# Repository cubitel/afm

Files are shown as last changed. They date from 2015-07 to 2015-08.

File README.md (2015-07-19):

DIY Atomic Force Microscope
---------------------------

DIY Atomic Force Microscope / Scanning Tunneling Microscope project.
More information can be found in [Project page](http://npk.cubitel.org/?/hardware/afm) (in Russian).

Please note that this project is under development yet.

### Hardware

Hardware folder contains hardware design files.

_Design tools_
- Schematic, PCB -- KiCAD
- 3D parts -- FreeCAD

### Firmware

Firmware folder contains firmware source files for STM32F407 controller.
Firmware using FreeRTOS and STM32 USB stack (bundled with the source tree).

### Software

Software folder contains control application source files.
Software using wxWidgets and libusb and designed to be cross-platform,
but current Makefile assumes Windows/MinGW.

_Build requirements_
- TDM-GCC
- wxWidgets
- libusb

### License
GPLv3

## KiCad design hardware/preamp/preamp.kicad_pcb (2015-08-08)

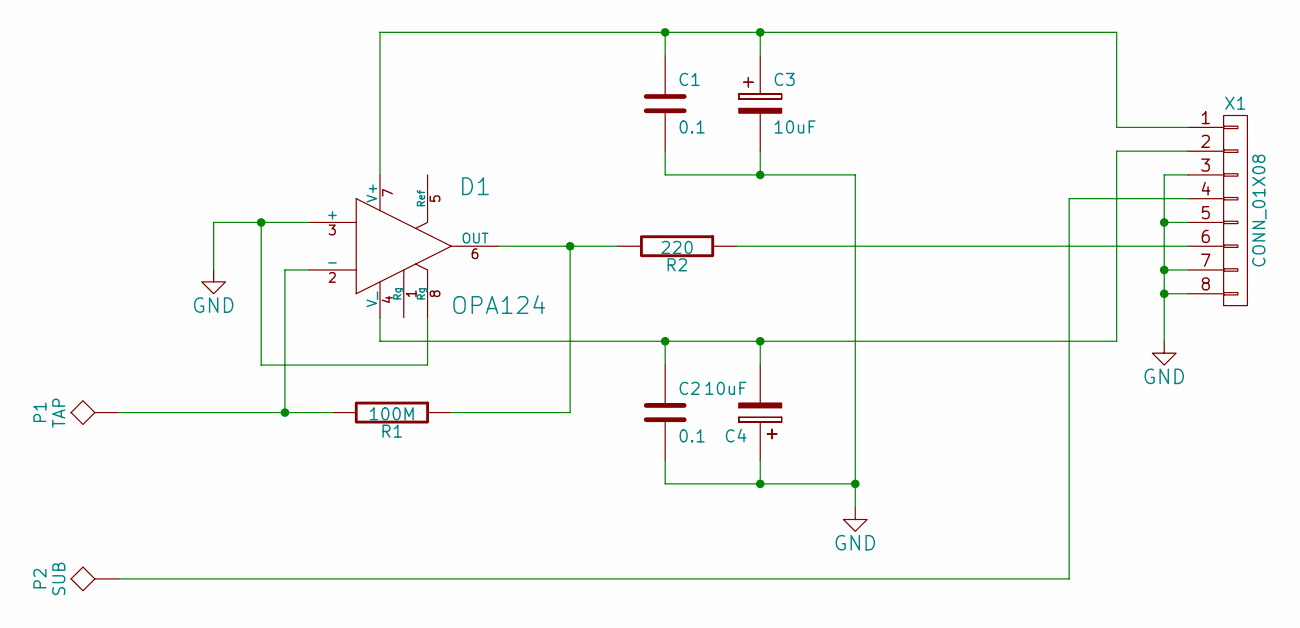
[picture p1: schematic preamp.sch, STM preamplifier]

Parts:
C1, C2: 0.1; C_0805
C3, C4: 10uF; TantalC_SizeA_EIA-3216_HandSoldering
D1: OPA124; SOIC-8-N
P1: TAP; Pin_Header_Straight_1x01
P2: SUB; Pin_Header_Straight_1x01
R1: 100M; R_0805
R2: 220; R_0805
X1: CONN_01X08; Pin_Header_Straight_1x08

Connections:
GND: C1.2, C2.2, C3.2, C4.1, D1.3 (+), D1.8 (Rg), X1.3, X1.5, X1.7, X1.8
unnamed: C1.1, C3.1, D1.7 (V+), X1.1
unnamed: C2.1, C4.2, D1.4 (V_), X1.2
unnamed: D1.2 (-), P1.1, R1.2
unnamed: D1.6 (OUT), R1.1, R2.2
unnamed: P2.1, X1.4
unnamed: R2.1, X1.6

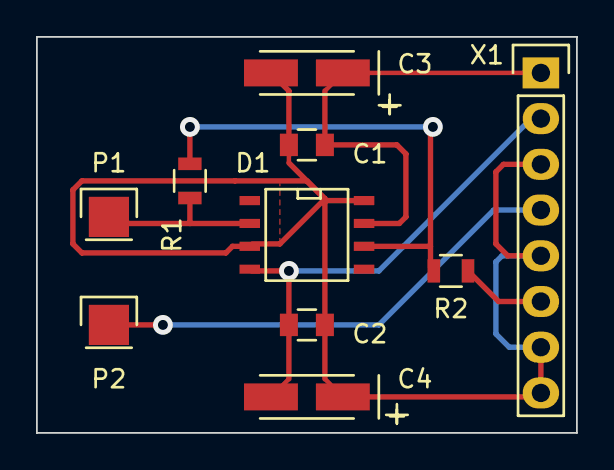
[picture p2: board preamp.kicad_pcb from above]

Board: 2 copper layers, 30.0 x 22.0 mm, 10 parts (0 on the bottom side), 7 nets.

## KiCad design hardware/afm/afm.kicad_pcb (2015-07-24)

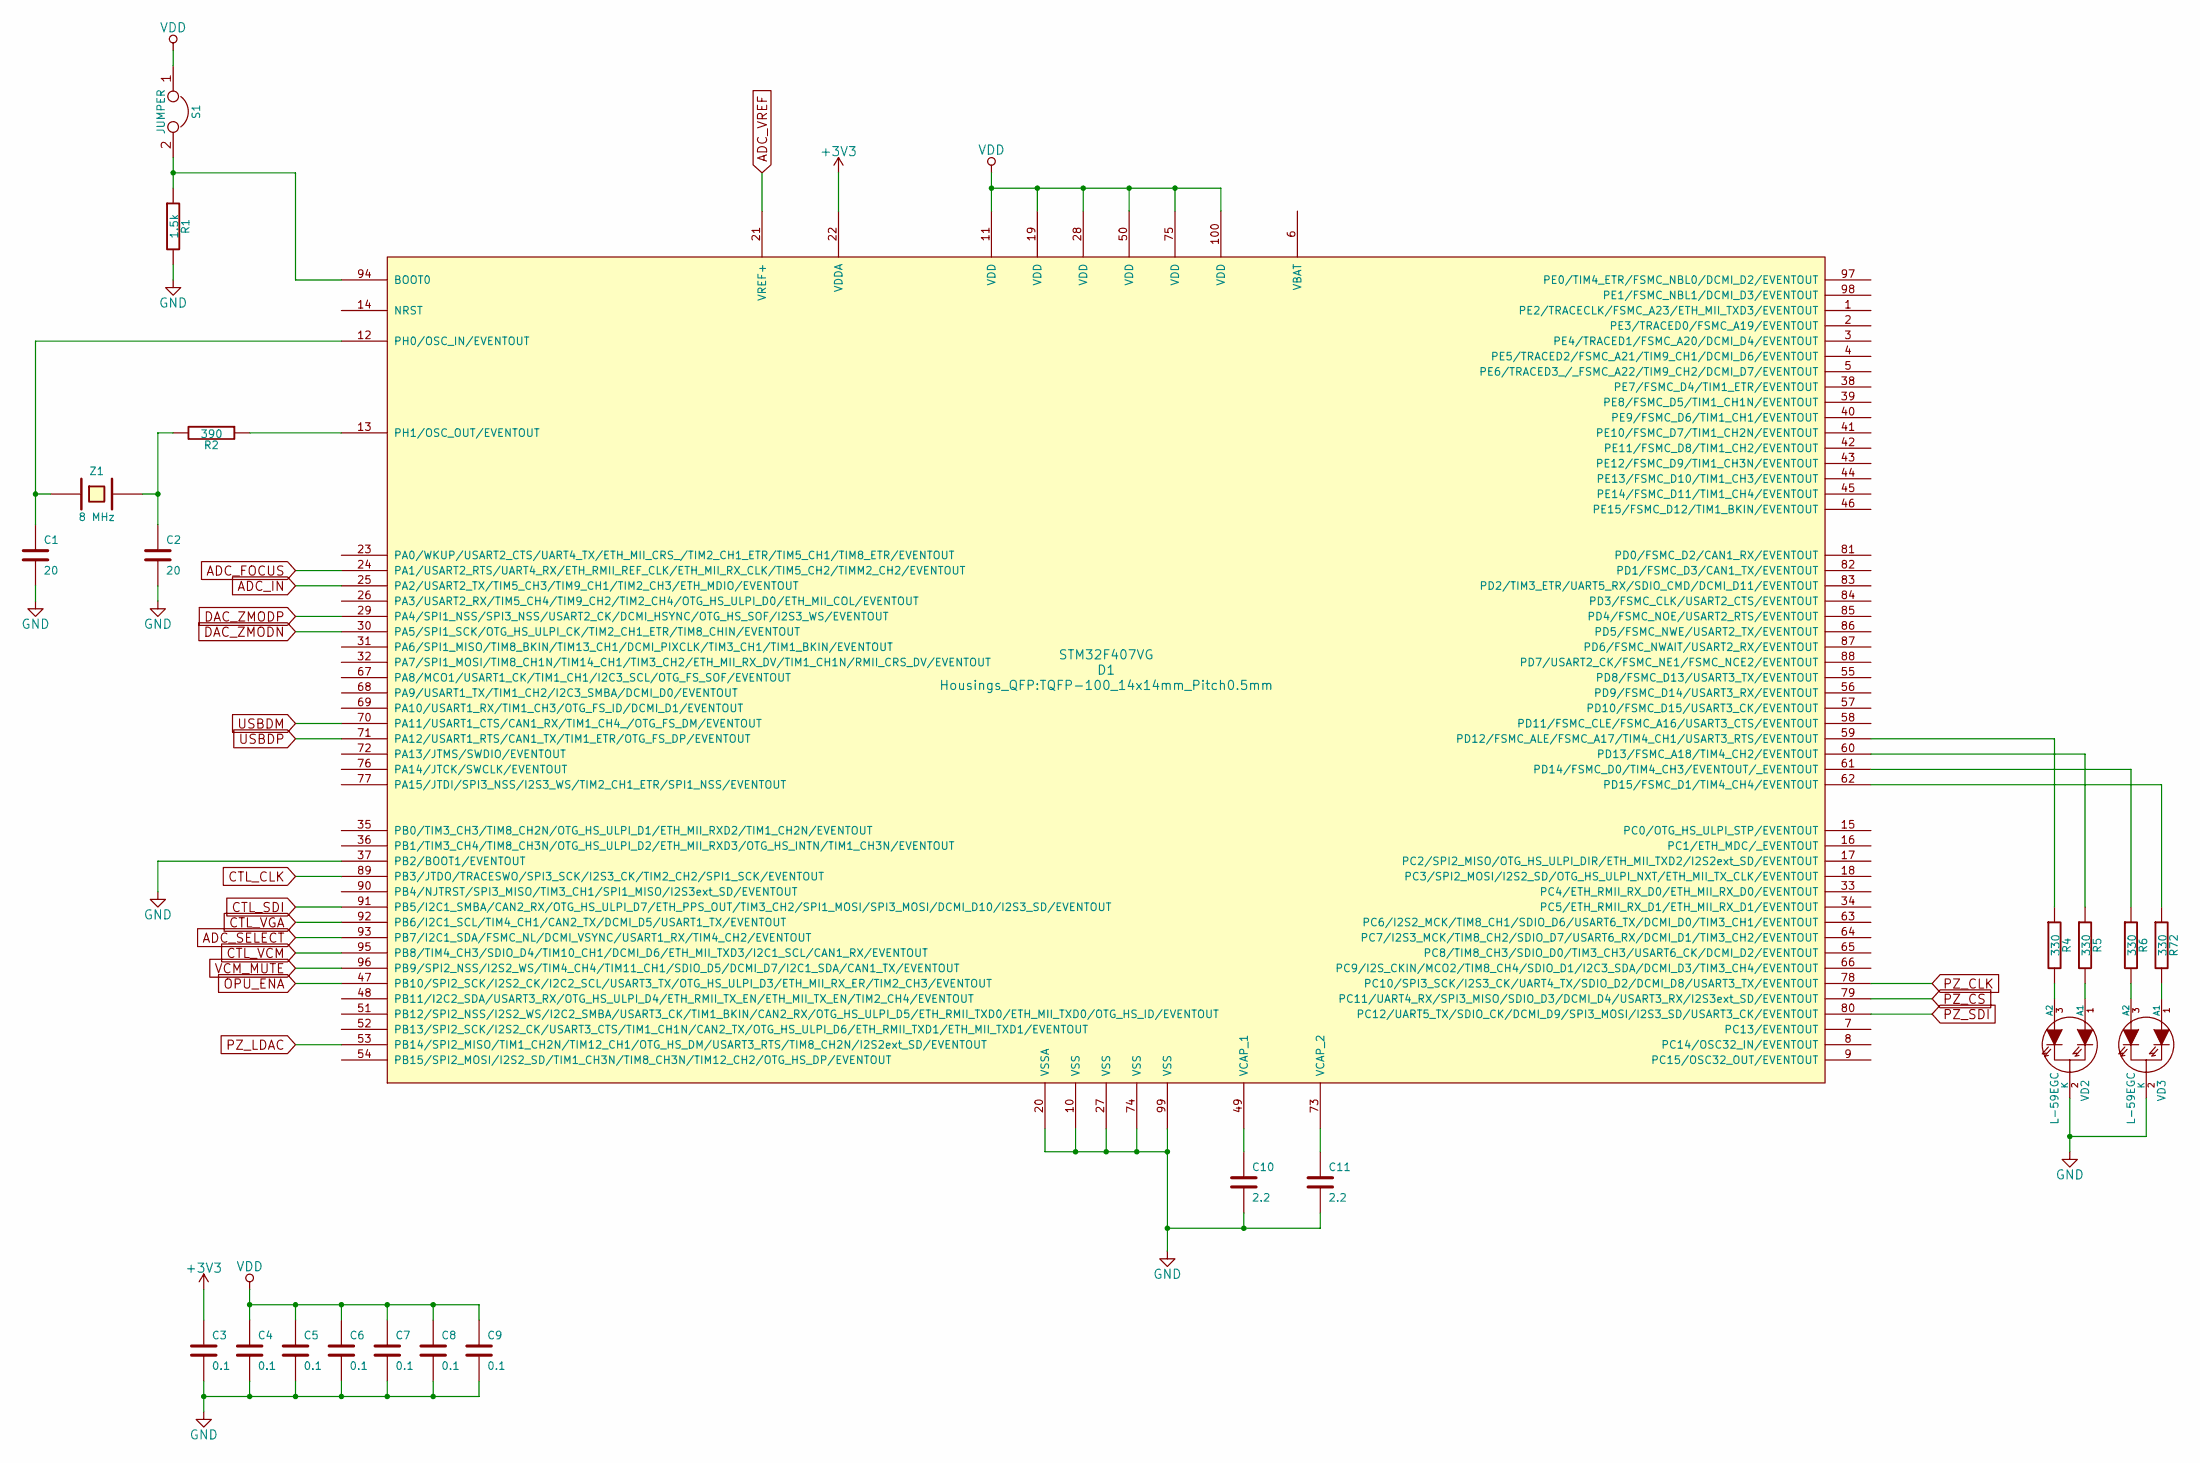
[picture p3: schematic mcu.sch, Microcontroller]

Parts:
C1, C2: 20; C_0603_HandSoldering
C3, C4, C5, C6, C7, C8, C9: 0.1; C_0603_HandSoldering
C10, C11: 2.2; C_0805_HandSoldering
D1: STM32F407VG; TQFP-100_14x14mm_Pitch0.5mm
R1: 1.5k; R_0603_HandSoldering
R2: 390; R_0603_HandSoldering
R4, R5, R6, R72: 330; R_0603_HandSoldering
S1: JUMPER; Pin_Header_Straight_1x02
VD2, VD3: L-59EGC; LED-5MM-3
Z1: 8 MHz; Crystal_HC49-SD_SMD

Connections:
+3V3: C3.1, D1.22 (VDDA); also elsewhere on the board
ADC_FOCUS: D1.24 (PA1/USART2_RTS/UART4_RX/ETH_RMII_REF_CL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); also elsewhere on the board
ADC_IN: D1.25 (PA2/USART2_TX/TIM5_CH3/TIM9_CH1/TIM2_CH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); also elsewhere on the board
ADC_SELECT: D1.93 (PB7/I2C1_SDA/FSMC_NL/DCMI_VSYNC/USART1_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); also elsewhere on the board
ADC_VREF: D1.21 (VREF+); also elsewhere on the board
CTL_CLK: D1.89 (PB3/JTDO/TRACESWO/SPI3_SCK/I2S3_CK/TIM2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); also elsewhere on the board
CTL_SDI: D1.91 (PB5/I2C1_SMBA/CAN2_RX/OTG_HS_ULPI_D7/ET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); also elsewhere on the board
CTL_VCM: D1.95 (PB8/TIM4_CH3/SDIO_D4/TIM10_CH1/DCMI_D6/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); also elsewhere on the board
CTL_VGA: D1.92 (PB6/I2C1_SCL/TIM4_CH1/CAN2_TX/DCMI_D5/U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); also elsewhere on the board
DAC_ZMODN: D1.30 (PA5/SPI1_SCK/OTG_HS_ULPI_CK/TIM2_CH1_ET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); also elsewhere on the board
DAC_ZMODP: D1.29 (PA4/SPI1_NSS/SPI3_NSS/USART2_CK/DCMI_HS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); also elsewhere on the board
GND: C1.2, C2.2, C3.2, C4.2, C5.2, C6.2, C7.2, C8.2, C9.2, C10.2, C11.2, D1.10 (VSS), D1.20 (VSSA), D1.27 (VSS), D1.37 (PB2/BOOT1/EVENTOUT), D1.74 (VSS), D1.99 (VSS), R1.2, VD2.2 (K), VD3.2 (K); also elsewhere on the board
unnamed: C1.1, D1.12 (PH0/OSC_IN/EVENTOUT), Z1.1
unnamed: C2.1, R2.2, Z1.2
unnamed: C10.1, D1.49 (VCAP_1)
unnamed: C11.1, D1.73 (VCAP_2)
unnamed: D1.13 (PH1/OSC_OUT/EVENTOUT), R2.1
unnamed: D1.59 (PD12/FSMC_ALE/FSMC_A17/TIM4_CH1/USART3_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), R4.1
unnamed: D1.60 (PD13/FSMC_A18/TIM4_CH2/EVENTOUT), R5.1
unnamed: D1.61 (PD14/FSMC_D0/TIM4_CH3/EVENTOUT/_EVENTOUT), R6.1
unnamed: D1.62 (PD15/FSMC_D1/TIM4_CH4/EVENTOUT), R72.1
unnamed: D1.94 (BOOT0), R1.1, S1.2
unnamed: R4.2, VD2.3 (A2)
unnamed: R5.2, VD2.1 (A1)
unnamed: R6.2, VD3.3 (A2)
unnamed: R72.2, VD3.1 (A1)
OPU_ENA: D1.47 (PB10/SPI2_SCK/I2S2_CK/I2C2_SCL/USART3_T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); also elsewhere on the board
PZ_CLK: D1.78 (PC10/SPI3_SCK/I2S3_CK/UART4_TX/SDIO_D2/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); also elsewhere on the board
PZ_CS: D1.79 (PC11/UART4_RX/SPI3_MISO/SDIO_D3/DCMI_D4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); also elsewhere on the board
PZ_LDAC: D1.53 (PB14/SPI2_MISO/TIM1_CH2N/TIM12_CH1/OTG_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); also elsewhere on the board
PZ_SDI: D1.80 (PC12/UART5_TX/SDIO_CK/DCMI_D9/SPI3_MOSI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); also elsewhere on the board
USBDM: D1.70 (PA11/USART1_CTS/CAN1_RX/TIM1_CH4_/OTG_F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); also elsewhere on the board
USBDP: D1.71 (PA12/USART1_RTS/CAN1_TX/TIM1_ETR/OTG_FS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); also elsewhere on the board
VCM_MUTE: D1.96 (PB9/SPI2_NSS/I2S2_WS/TIM4_CH4/TIM11_CH1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); also elsewhere on the board
VDD: C4.1, C5.1, C6.1, C7.1, C8.1, C9.1, D1.11 (VDD), D1.19 (VDD), D1.28 (VDD), D1.50 (VDD), D1.75 (VDD), D1.100 (VDD), S1.1; also elsewhere on the board

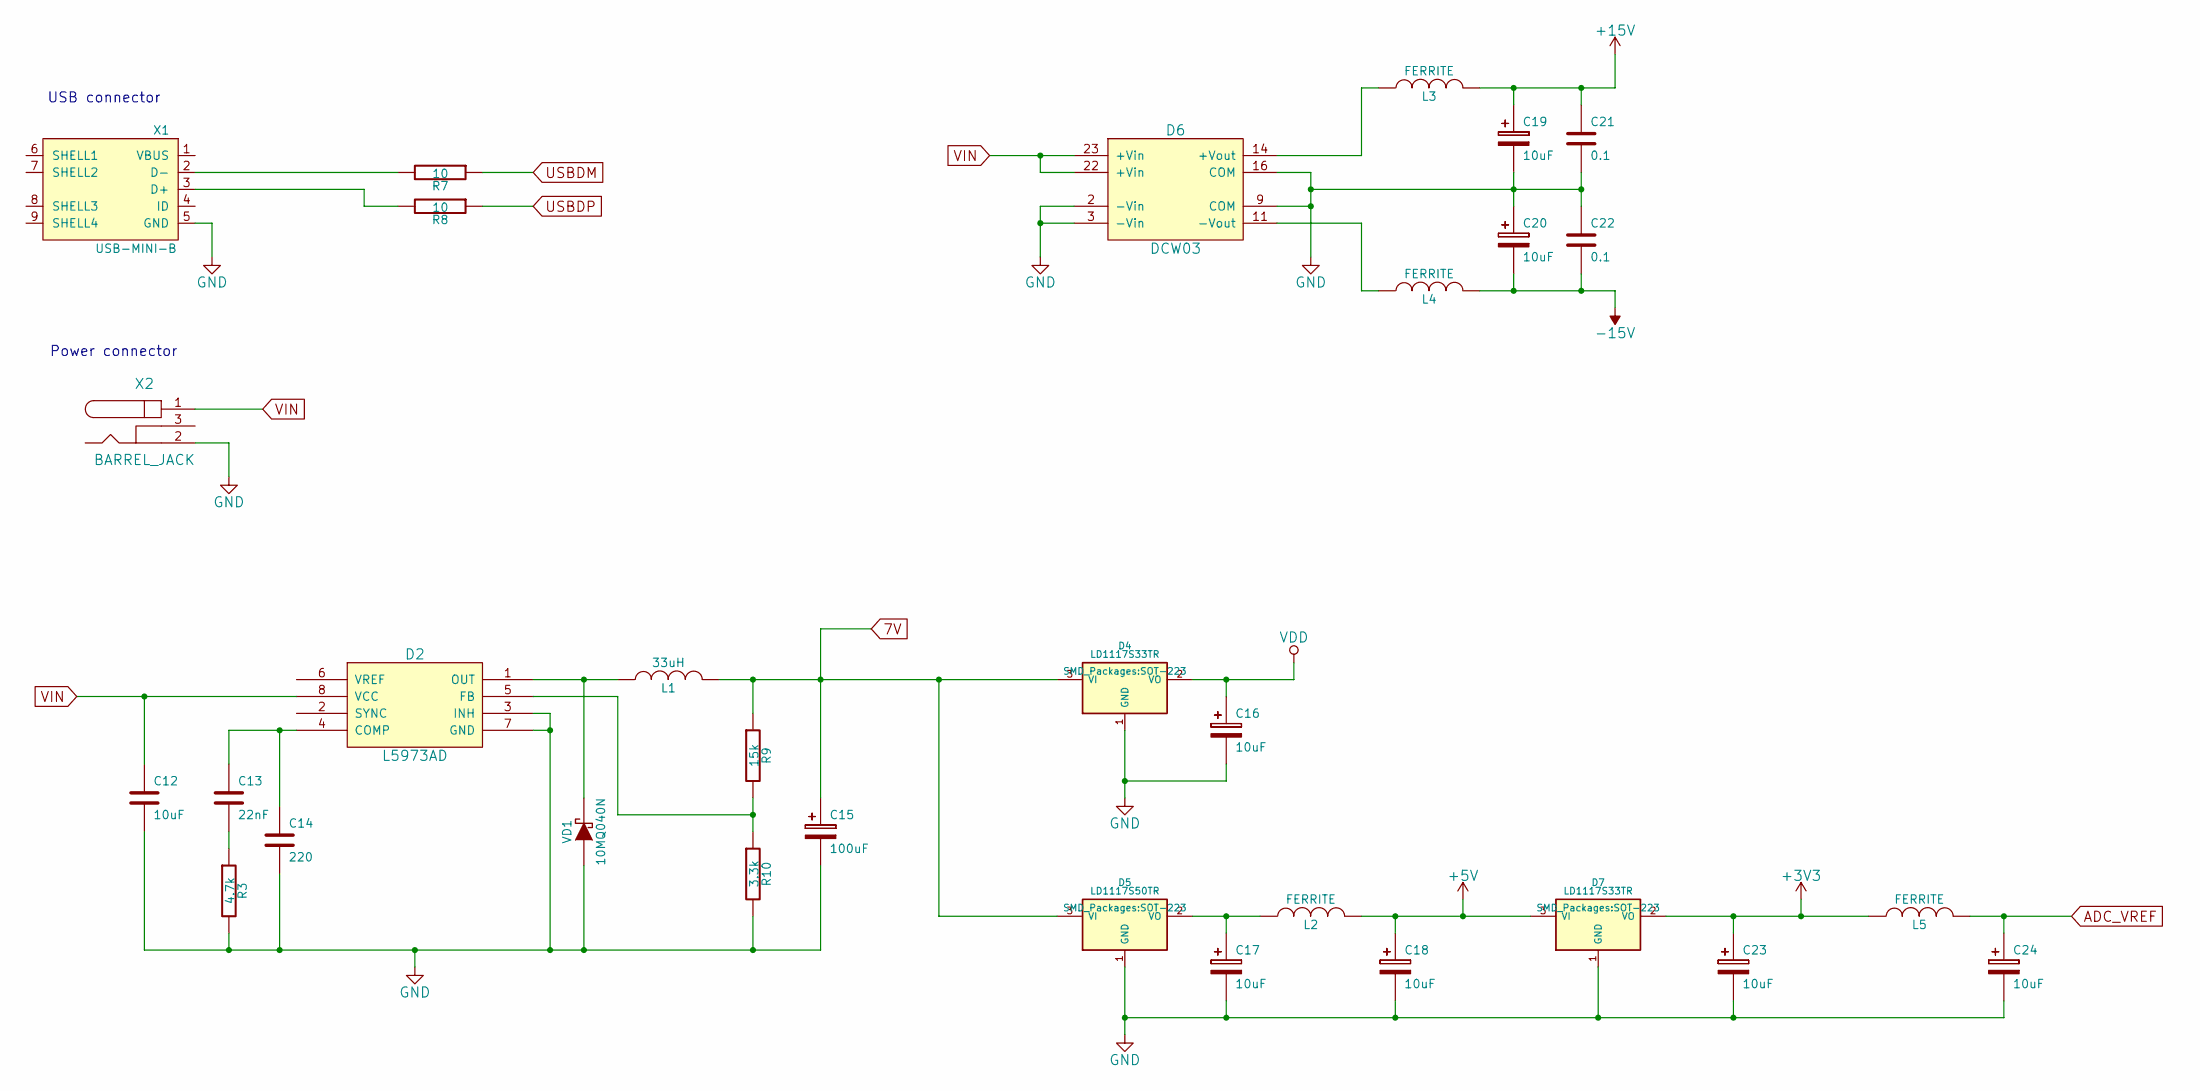
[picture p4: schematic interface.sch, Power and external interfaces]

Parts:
C12: 10uF; C_1206_HandSoldering
C13: 22nF; C_0603_HandSoldering
C14: 220; C_0603_HandSoldering
C15: 100uF; TantalC_SizeD_EIA-7343_HandSoldering
C16, C17, C18, C23, C24: 10uF; TantalC_SizeB_EIA-3528_HandSoldering
C19, C20: 10uF; TantalC_SizeD_EIA-7343_HandSoldering
C21, C22: 0.1; C_0603_HandSoldering
D2: L5973AD; SOIC-8-1EP_3.9x4.9mm_Pitch1.27mm
D4, D7: LD1117S33TR; SOT-223
D5: LD1117S50TR; SOT-223
D6: DCW03; DIP-24__600
L1: 33uH; Neosid_Inductor_SM-PIC0612H
L2, L3, L4, L5: FERRITE; R_1206_HandSoldering
R3: 4.7k; R_0603_HandSoldering
R7, R8: 10; R_0603_HandSoldering
R9: 15k; R_0603_HandSoldering
R10: 3.3k; R_0603_HandSoldering
VD1: 10MQ040N; Diode-SMA_Handsoldering
X1: USB-MINI-B; USB_Mini-B
X2: BARREL_JACK; JACK_ALIM

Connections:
7V: C15.1, D4.3 (VI), D5.3 (VI), L1.2, R9.1
+3V3: C23.1, D7.2 (VO), L5.1; also elsewhere on the board
+5V: C18.1, D7.3 (VI), L2.2; also elsewhere on the board
+15V: C19.1, C21.1, L3.2; also elsewhere on the board
-15V: C20.2, C22.2, L4.2; also elsewhere on the board
ADC_VREF: C24.1, L5.2; also elsewhere on the board
GND: C12.2, C14.2, C15.2, C16.2, C17.2, C18.2, C19.2, C20.1, C21.2, C22.1, C23.2, C24.2, D2.3 (INH), D2.7 (GND), D4.1 (GND), D5.1 (GND), D6.2 (-Vin), D6.3 (-Vin), D6.9 (COM), D6.16 (COM), D7.1 (GND), R3.2, R10.2, VD1.1 (A), X1.5 (GND), X2.2; also elsewhere on the board
unnamed: C13.1, C14.1, D2.4 (COMP)
unnamed: C13.2, R3.1
unnamed: C17.1, D5.2 (VO), L2.1
unnamed: D2.1 (OUT), L1.1, VD1.2 (K)
unnamed: D2.5 (FB), R9.2, R10.1
unnamed: D6.11 (-Vout), L4.1
unnamed: D6.14 (+Vout), L3.1
unnamed: R7.2, X1.2 (D-)
unnamed: R8.2, X1.3 (D+)
USBDM: R7.1; also elsewhere on the board
USBDP: R8.1; also elsewhere on the board
VDD: C16.1, D4.2 (VO); also elsewhere on the board
VIN: C12.1, D2.8 (VCC), D6.22 (+Vin), D6.23 (+Vin), X2.1

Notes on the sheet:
USB connector
Power connector

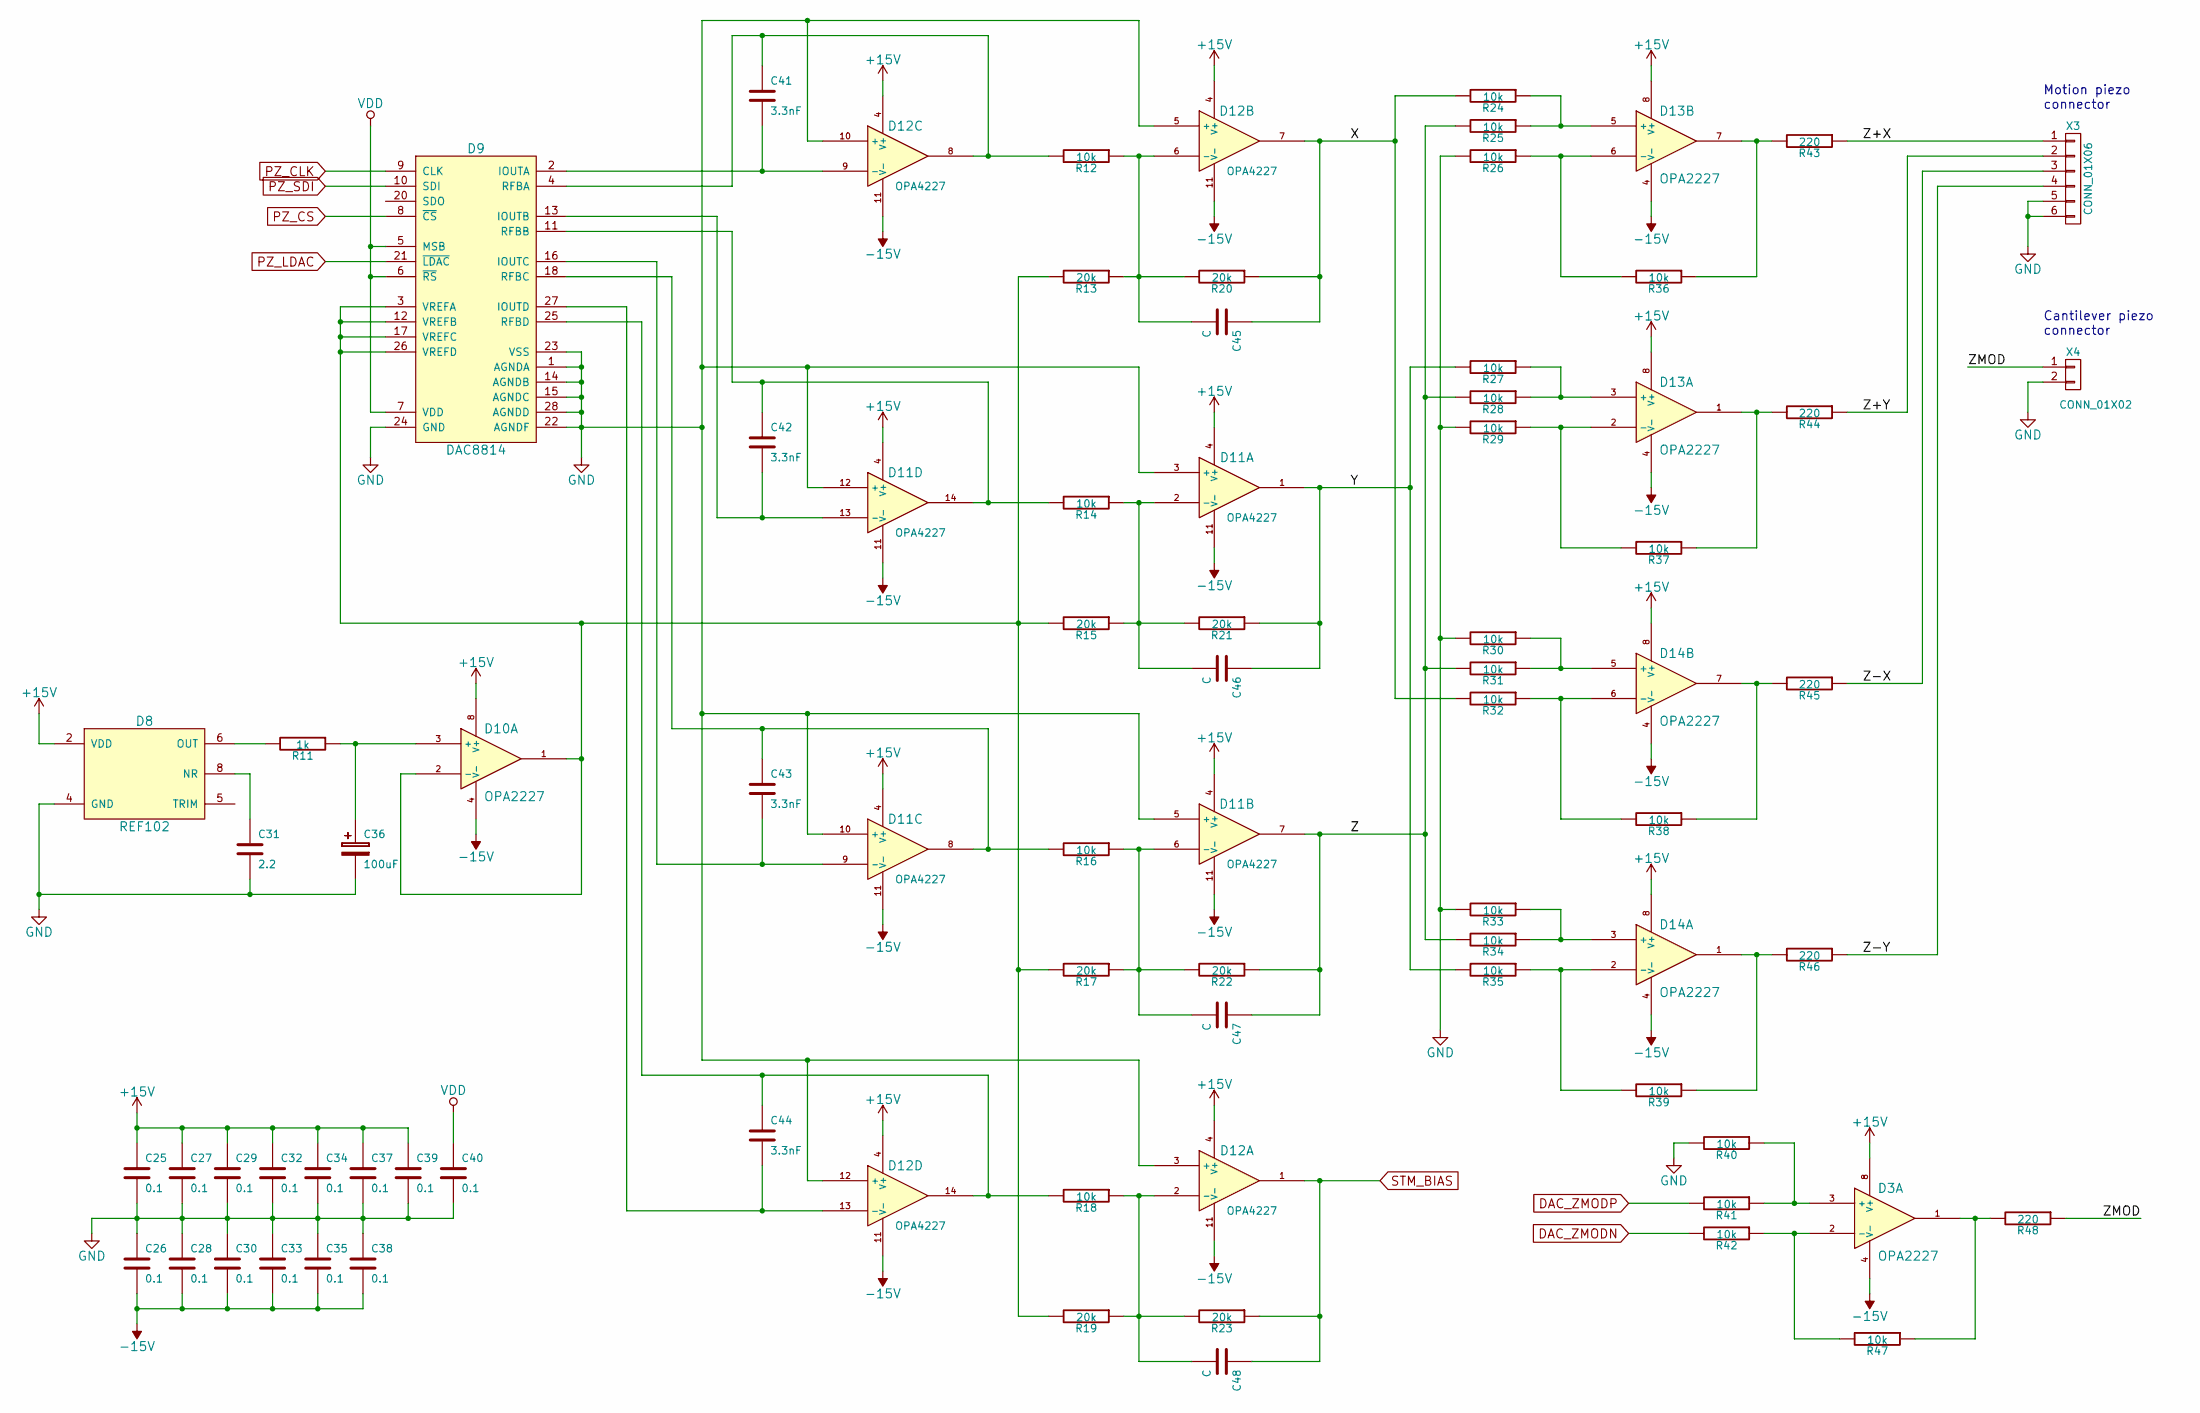
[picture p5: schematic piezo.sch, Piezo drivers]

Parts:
C25, C26, C27, C28, C29, C30, C32, C33, C34, C35, C37, C38, C39, C40: 0.1; C_0603_HandSoldering
C31: 2.2; C_0603_HandSoldering
C36: 100uF; TantalC_SizeD_EIA-7343_HandSoldering
C41, C42, C43, C44: 3.3nF; C_0603_HandSoldering
C45, C46, C47, C48: C; C_0603_HandSoldering
D3, D10, D13, D14: OPA2227; SOIC-8-N
D8: REF102; SOIC-8-N
D9: DAC8814; SSOP-28_5.3x10.2mm_Pitch0.65mm
D11, D12: OPA4227; SOIC-14_N
R11: 1k; R_0603_HandSoldering
R12, R14, R16, R18, R24, R25, R26, R27, R28, R29, R30, R31, R32, R33, R34, R35, R36, R37, R38, R39, R40, R41, R42, R47: 10k; R_0603_HandSoldering
R13, R15, R17, R19, R20, R21, R22, R23: 20k; R_0603_HandSoldering
R43, R44, R45, R46, R48: 220; R_0603_HandSoldering
X3: CONN_01X06; Pin_Header_Straight_1x06
X4: CONN_01X02; Pin_Header_Straight_1x02

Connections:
+15V: C25.1, C27.1, C29.1, C32.1, C34.1, C37.1, C39.1, D3.8 (V+), D8.2 (VDD), D10.8 (V+), D11.4 (V+), D12.4 (V+), D13.8 (V+), D14.8 (V+); also elsewhere on the board
-15V: C26.2, C28.2, C30.2, C33.2, C35.2, C38.2, D3.4 (V-), D10.4 (V-), D11.11 (V-), D12.11 (V-), D13.4 (V-), D14.4 (V-); also elsewhere on the board
/Piezo drivers/X: C45.1, D12.7, R20.1, R24.2, R32.2
/Piezo drivers/Y: C46.1, D11.1, R21.1, R27.2, R35.2
/Piezo drivers/Z: C47.1, D11.7, R22.1, R25.2, R28.2, R31.2, R34.2
/Piezo drivers/Z+X: R43.1, X3.1
/Piezo drivers/Z+Y: R44.1, X3.2
/Piezo drivers/Z-X: R45.1, X3.3
/Piezo drivers/Z-Y: R46.1, X3.4
/Piezo drivers/ZMOD: R48.1, X4.1
DAC_ZMODN: R42.2; also elsewhere on the board
DAC_ZMODP: R41.2; also elsewhere on the board
GND: C25.2, C26.1, C27.2, C28.1, C29.2, C30.1, C31.2, C32.2, C33.1, C34.2, C35.1, C36.2, C37.2, C38.1, C39.2, C40.2, D8.4 (GND), D9.1 (AGNDA), D9.14 (AGNDB), D9.15 (AGNDC), D9.22 (AGNDF), D9.23 (VSS), D9.24 (GND), D9.28 (AGNDD), D11.3 (+), D11.5 (+), D11.10 (+), D11.12 (+), D12.3 (+), D12.5 (+), D12.10 (+), D12.12 (+), R26.2, R29.2, R30.2, R33.2, R40.2, X3.5, X3.6, X4.2; also elsewhere on the board
unnamed: C31.1, D8.8 (NR)
unnamed: C36.1, D10.3 (+), R11.1
unnamed: C41.1, D9.4 (RFBA), D12.8, R12.2
unnamed: C41.2, D9.2 (IOUTA), D12.9 (-)
unnamed: C42.1, D9.11 (RFBB), D11.14, R14.2
unnamed: C42.2, D9.13 (IOUTB), D11.13 (-)
unnamed: C43.1, D9.18 (RFBC), D11.8, R16.2
unnamed: C43.2, D9.16 (IOUTC), D11.9 (-)
unnamed: C44.1, D9.25 (RFBD), D12.14, R18.2
unnamed: C44.2, D9.27 (IOUTD), D12.13 (-)
unnamed: C45.2, D12.6 (-), R12.1, R13.1, R20.2
unnamed: C46.2, D11.2 (-), R14.1, R15.1, R21.2
unnamed: C47.2, D11.6 (-), R16.1, R17.1, R22.2
unnamed: C48.2, D12.2 (-), R18.1, R19.1, R23.2
unnamed: D3.1, R47.1, R48.2
unnamed: D3.2 (-), R42.1, R47.2
unnamed: D3.3 (+), R40.1, R41.1
unnamed: D8.6 (OUT), R11.2
unnamed: D9.3 (VREFA), D9.12 (VREFB), D9.17 (VREFC), D9.26 (VREFD), D10.1, D10.2 (-), R13.2, R15.2, R17.2, R19.2
unnamed: D13.1, R37.1, R44.2
unnamed: D13.2 (-), R29.1, R37.2
unnamed: D13.3 (+), R27.1, R28.1
unnamed: D13.5 (+), R24.1, R25.1
unnamed: D13.6 (-), R26.1, R36.2
unnamed: D13.7, R36.1, R43.2
unnamed: D14.1, R39.1, R46.2
unnamed: D14.2 (-), R35.1, R39.2
unnamed: D14.3 (+), R33.1, R34.1
unnamed: D14.5 (+), R30.1, R31.1
unnamed: D14.6 (-), R32.1, R38.2
unnamed: D14.7, R38.1, R45.2
PZ_CLK: D9.9 (CLK); also elsewhere on the board
PZ_CS: D9.8 (~CS); also elsewhere on the board
PZ_LDAC: D9.21 (~LDAC); also elsewhere on the board
PZ_SDI: D9.10 (SDI); also elsewhere on the board
STM_BIAS: C48.1, D12.1, R23.1; also elsewhere on the board
VDD: C40.1, D9.5 (MSB), D9.6 (~RS), D9.7 (VDD); also elsewhere on the board

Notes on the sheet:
Motion piezo connector
Cantilever piezo connector

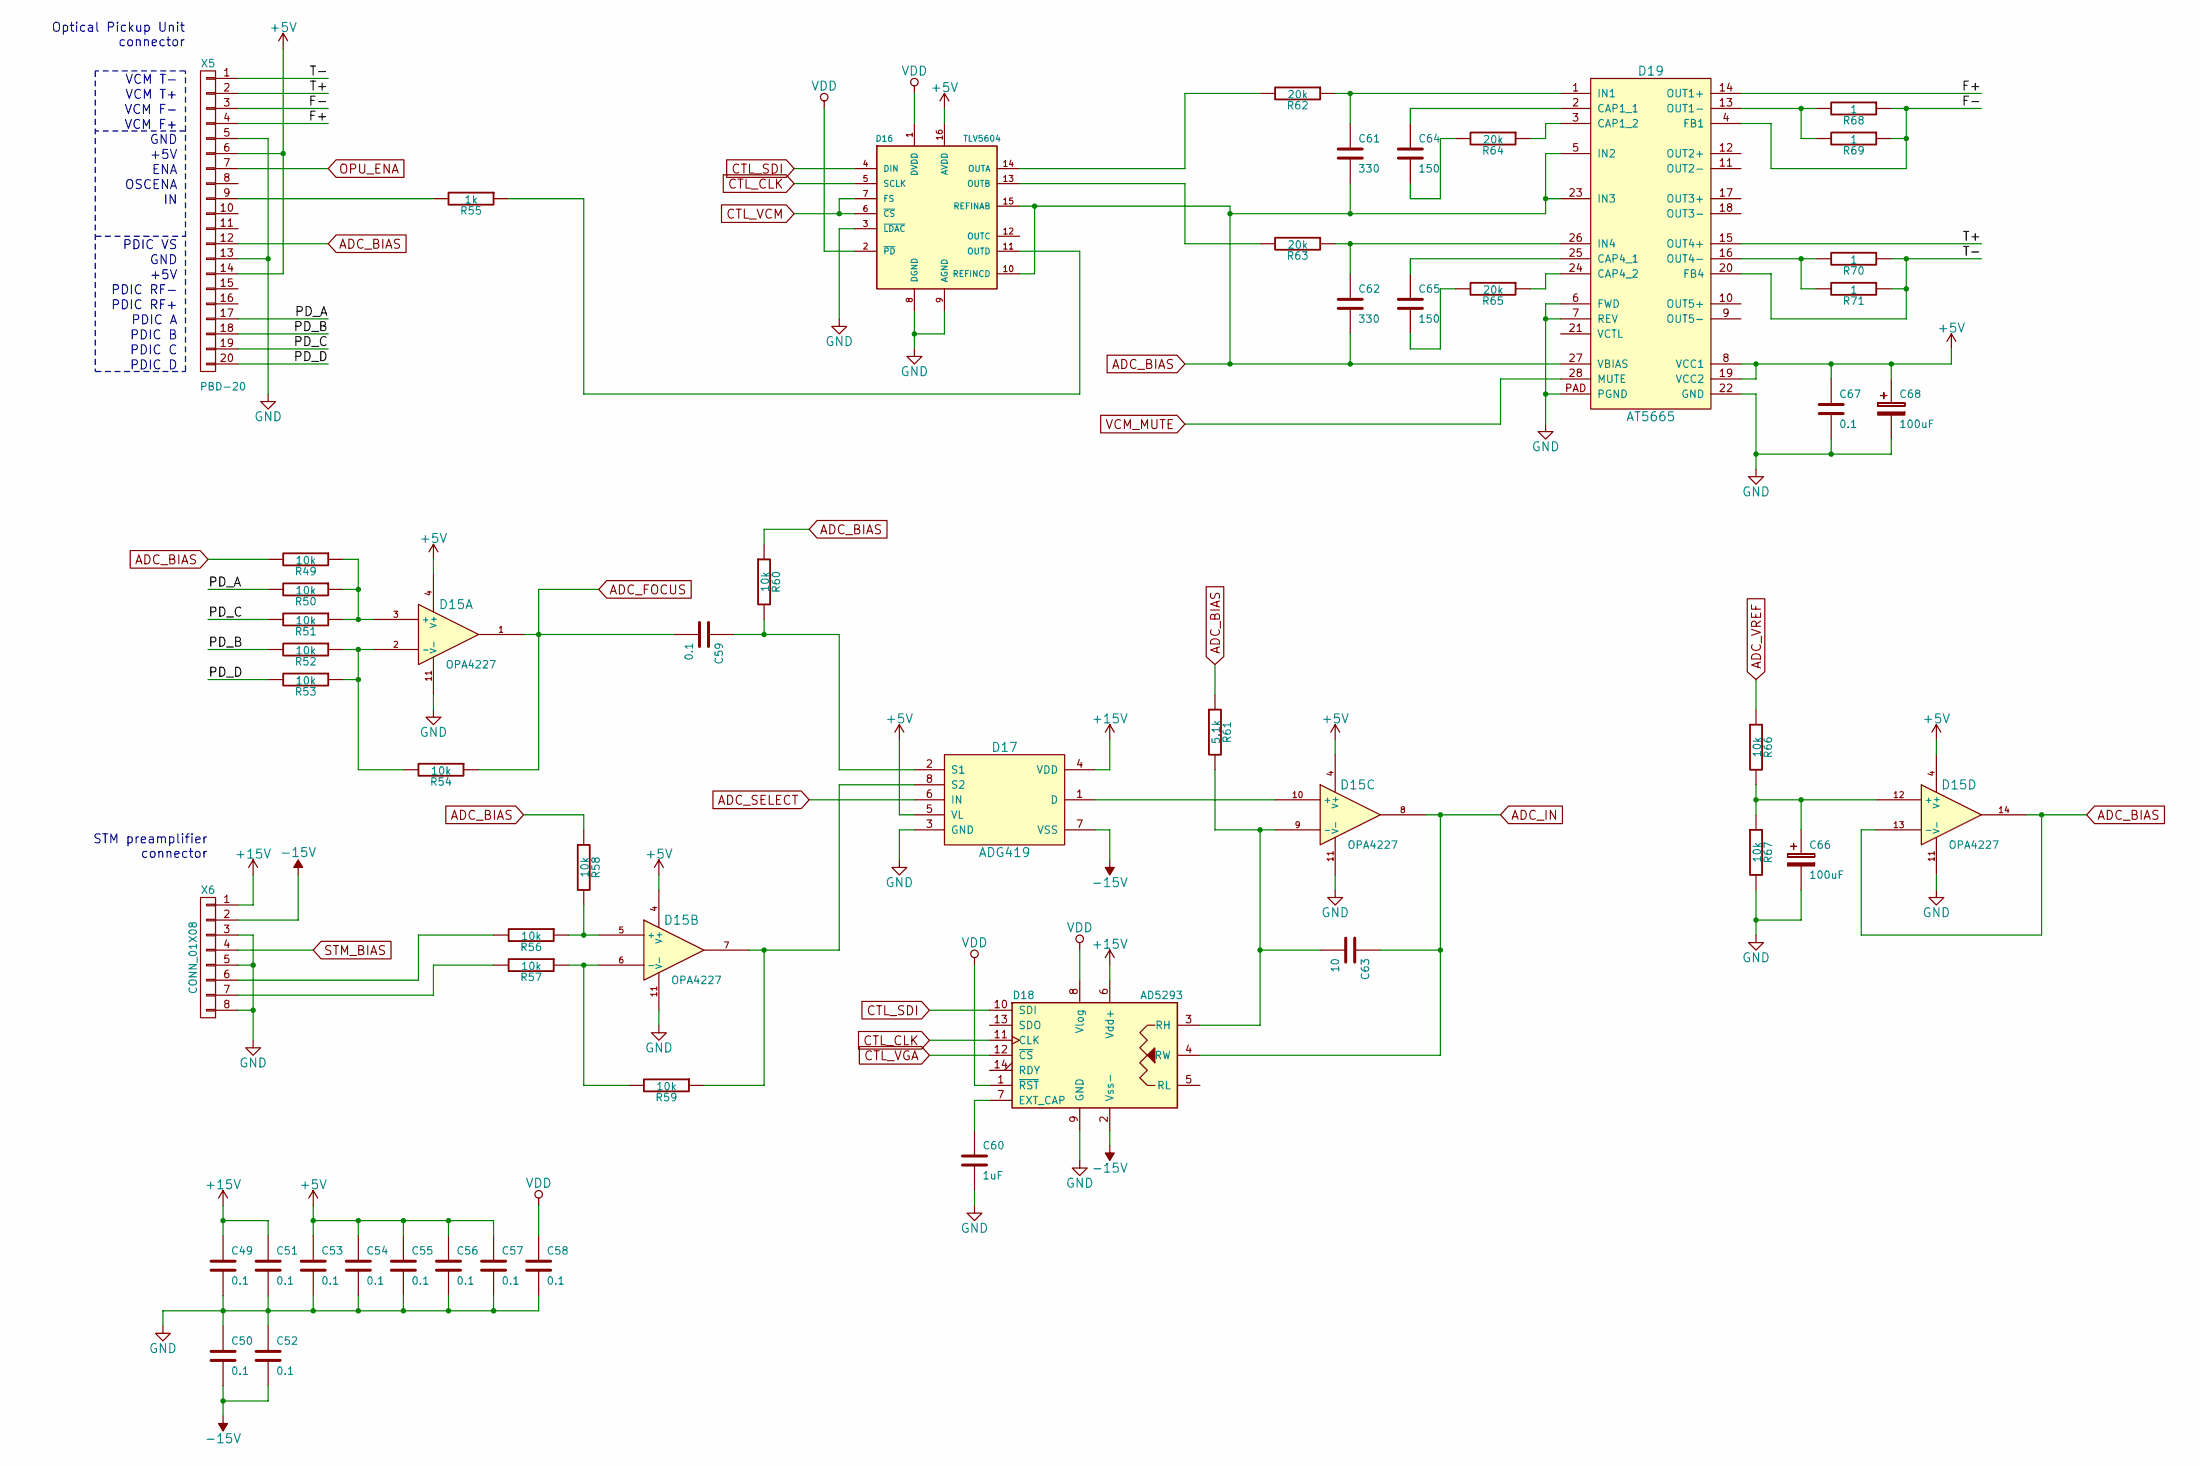
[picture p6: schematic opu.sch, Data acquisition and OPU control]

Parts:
C49, C50, C51, C52, C53, C54, C55, C56, C57, C58, C59, C67: 0.1; C_0603_HandSoldering
C60: 1uF; C_0805_HandSoldering
C61, C62: 330; C_0603_HandSoldering
C63: 10; C_0603_HandSoldering
C64, C65: 150; C_0603_HandSoldering
C66, C68: 100uF; TantalC_SizeD_EIA-7343_HandSoldering
D15: OPA4227; SOIC-14_N
D16: TLV5604; SOIC-16_3.9x9.9mm_Pitch1.27mm
D17: ADG419; SOIC-8_3.9x4.9mm_Pitch1.27mm
D18: AD5293; TSSOP-14_4.4x5mm_Pitch0.65mm
D19: AT5665; SOIC-28
R49, R50, R51, R52, R53, R54, R56, R57, R58, R59, R60, R66, R67: 10k; R_0603_HandSoldering
R55: 1k; R_0603_HandSoldering
R61: 5.1k; R_0603_HandSoldering
R62, R63, R64, R65: 20k; R_0603_HandSoldering
R68, R69, R70, R71: 1; R_0805_HandSoldering
X5: PBD-20; Pin_Header_Straight_2x10
X6: CONN_01X08; Pin_Header_Straight_1x08

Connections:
+5V: C53.1, C54.1, C55.1, C56.1, C57.1, C67.1, C68.1, D15.4 (V+), D16.16 (AVDD), D17.5 (VL), D19.8 (VCC1), D19.19 (VCC2), X5.6, X5.14; also elsewhere on the board
+15V: C49.1, C51.1, D17.4 (VDD), D18.6 (Vdd+), X6.1; also elsewhere on the board
-15V: C50.2, C52.2, D17.7 (VSS), D18.2 (Vss-), X6.2; also elsewhere on the board
/OPU interface/F+: D19.14 (OUT1+), X5.4
/OPU interface/F-: D19.4 (FB1), R68.1, R69.1, X5.3
/OPU interface/PD_A: R50.2, X5.17
/OPU interface/PD_B: R52.2, X5.18
/OPU interface/PD_C: R51.2, X5.19
/OPU interface/PD_D: R53.2, X5.20
/OPU interface/T+: D19.15 (OUT4+), X5.2
/OPU interface/T-: D19.20 (FB4), R70.1, R71.1, X5.1
ADC_BIAS: C61.2, C62.2, D15.13 (-), D15.14, D16.10 (REFINCD), D16.15 (REFINAB), D19.5 (IN2), D19.23 (IN3), D19.27 (VBIAS), R49.2, R58.1, R60.1, R61.1, X5.12
ADC_FOCUS: C59.2, D15.1, R54.1; also elsewhere on the board
ADC_IN: C63.1, D15.8, D18.4 (RW); also elsewhere on the board
ADC_SELECT: D17.6 (IN); also elsewhere on the board
ADC_VREF: R66.1; also elsewhere on the board
CTL_CLK: D16.5 (SCLK), D18.11 (CLK); also elsewhere on the board
CTL_SDI: D16.4 (DIN), D18.10 (SDI); also elsewhere on the board
CTL_VCM: D16.6 (~CS), D16.7 (FS); also elsewhere on the board
CTL_VGA: D18.12 (~CS~); also elsewhere on the board
GND: C49.2, C50.1, C51.2, C52.1, C53.2, C54.2, C55.2, C56.2, C57.2, C58.2, C60.2, C66.2, C67.2, C68.2, D15.11 (V-), D16.3 (~LDAC), D16.8 (DGND), D16.9 (AGND), D17.3 (GND), D18.9 (GND), D19.6 (FWD), D19.7 (REV), D19.22 (GND), D19.PAD (PGND), R67.2, X5.5, X5.13, X6.3, X6.5, X6.8; also elsewhere on the board
unnamed: C59.1, D17.2 (S1), R60.2
unnamed: C60.1, D18.7 (EXT_CAP)
unnamed: C61.1, D19.1 (IN1), R62.1
unnamed: C62.1, D19.26 (IN4), R63.1
unnamed: C63.2, D15.9 (-), D18.3 (RH), R61.2
unnamed: C64.1, D19.2 (CAP1_1)
unnamed: C64.2, R64.2
unnamed: C65.1, D19.25 (CAP4_1)
unnamed: C65.2, R65.2
unnamed: C66.1, D15.12 (+), R66.2, R67.1
unnamed: D15.2 (-), R52.1, R53.1, R54.2
unnamed: D15.3 (+), R49.1, R50.1, R51.1
unnamed: D15.5 (+), R56.1, R58.2
unnamed: D15.6 (-), R57.1, R59.2
unnamed: D15.7, D17.8 (S2), R59.1
unnamed: D15.10 (+), D17.1 (D)
unnamed: D16.11 (OUTD), R55.1
unnamed: D16.13 (OUTB), R63.2
unnamed: D16.14 (OUTA), R62.2
unnamed: D19.3 (CAP1_2), R64.1
unnamed: D19.13 (OUT1-), R68.2, R69.2
unnamed: D19.16 (OUT4-), R70.2, R71.2
unnamed: D19.24 (CAP4_2), R65.1
unnamed: R55.2, X5.9
unnamed: R56.2, X6.6
unnamed: R57.2, X6.7
OPU_ENA: X5.7; also elsewhere on the board
STM_BIAS: X6.4; also elsewhere on the board
VCM_MUTE: D19.28 (MUTE); also elsewhere on the board
VDD: C58.1, D16.1 (DVDD), D16.2 (~PD), D18.1 (~RST~), D18.8 (Vlog); also elsewhere on the board

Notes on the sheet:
VCM T-
VCM T+
VCM F-
VCM F+
GND
+5V
PDIC D
PDIC C
PDIC B
PDIC A
PDIC VS
ENA
OSCENA
PDIC RF+
PDIC RF-
Optical Pickup Unit connector
STM preamplifier connector

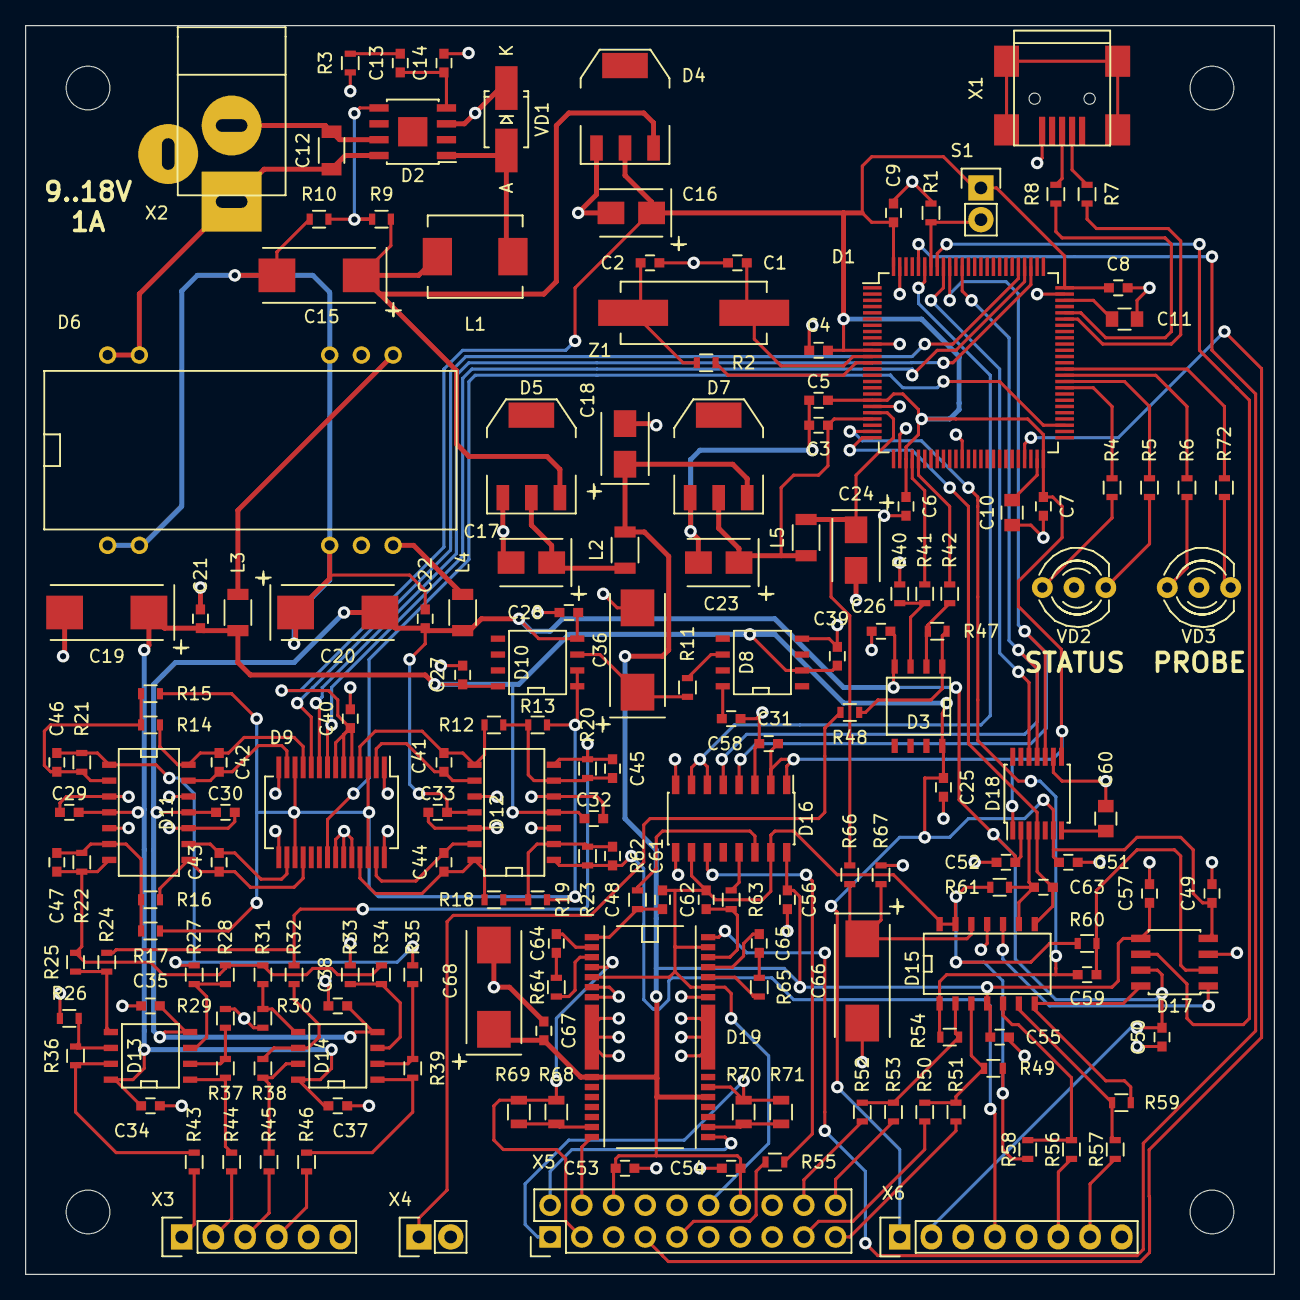
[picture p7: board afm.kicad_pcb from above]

Board: 2 copper layers, 100.0 x 100.0 mm, 175 parts (0 on the bottom side), 124 nets.

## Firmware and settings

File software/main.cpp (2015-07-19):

/* Copyright (c) 2015 Vasily Voropaev <vvg@cubitel.org>
 *
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
 */

#include <wx/wx.h>
#include <wx/intl.h>
#include <wx/progdlg.h>

#include "device.h"
#include "image.h"
#include "dfu.h"


#define UPDATE_TIMER_CONNECTED		500
#define UPDATE_TIMER_DISCONNECTED	2000


class MyApp: public wxApp
{
public:
	Device *afm;
    virtual bool OnInit();
    virtual int OnExit();
protected:
    wxLanguage m_lang;  // language specified by user
    wxLocale m_locale;  // locale we'll be using
private:
	void CheckDFU();
};

class MainFrame: public wxFrame
{
public:
    MainFrame(const wxString& title, const wxPoint& pos, const wxSize& size);
    void UpdateAFMState();
private:
    wxTimer *tmrUpdate;
    wxStaticText *stMicroType;
    wxStaticText *stHeightControl;
    wxStaticText *stHeightValue;
    wxButton *btnStart;
    void OnExit(wxCommandEvent& event);
    void OnAbout(wxCommandEvent& event);
    void OnRun(wxCommandEvent& event);
    void OnUpdateTimer(wxTimerEvent& evt);
    wxDECLARE_EVENT_TABLE();
};

enum
{
    ID_Run = 1,
    ID_UpdateTimer
};

wxBEGIN_EVENT_TABLE(MainFrame, wxFrame)
    EVT_MENU(wxID_EXIT,  MainFrame::OnExit)
    EVT_MENU(wxID_ABOUT, MainFrame::OnAbout)
    EVT_COMMAND(ID_Run, wxEVT_COMMAND_BUTTON_CLICKED, MainFrame::OnRun)
    EVT_TIMER(ID_UpdateTimer, MainFrame::OnUpdateTimer)
wxEND_EVENT_TABLE()

wxIMPLEMENT_APP(MyApp);



bool MyApp::OnInit()
{
	int i;
	char buf[100];

    if ( !wxApp::OnInit() )
        return false;

    m_lang = wxLANGUAGE_DEFAULT;
    m_locale.Init(m_lang, wxLOCALE_DONT_LOAD_DEFAULT);

    wxLocale::AddCatalogLookupPathPrefix("./lang");

    m_locale.AddCatalog("messages");
    m_locale.AddCatalog("wxstd");

    /* Create AFM device instance */
    afm = new Device();

    if (!afm->Connect()) CheckDFU();

    MainFrame *frame = new MainFrame(_("AFM Control"),
    		wxPoint(50, 50),
    		wxSize(450, 340) );
    frame->Show( true );

    return true;
}

int MyApp::OnExit()
{
	afm->Disconnect();
	return 0;
}

void MyApp::CheckDFU()
{
	if (!dfuOpen()) return;

	do {
		int answer = wxMessageBox(
				_("Working device is not found, but empty STM32 device is found. Do you want to download AFM firmware to that device?"),
				_("Firmware update"),
				wxYES_NO, NULL);

		if (answer != wxYES) break;

		wxFileDialog openFile(NULL, _("Open firmware file"), "", "firmware.bin",
				"Firmware files (*.bin)|*.bin", wxFD_OPEN | wxFD_FILE_MUST_EXIST);

		if (openFile.ShowModal() == wxID_CANCEL) break;

	} while(0);

	dfuClose();
}


MainFrame::MainFrame(const wxString& title, const wxPoint& pos, const wxSize& size)
        : wxFrame(NULL, wxID_ANY, title, pos, size, wxMINIMIZE_BOX | wxSYSTEM_MENU | wxCAPTION | wxCLOSE_BOX | wxCLIP_CHILDREN)
{
	/* Main menu */

    wxMenu *menuFile = new wxMenu;
    menuFile->Append(wxID_EXIT);

    wxMenu *menuHelp = new wxMenu;
    menuHelp->Append(wxID_ABOUT);

    wxMenuBar *menuBar = new wxMenuBar;
    menuBar->Append( menuFile, _("&File") );
    menuBar->Append( menuHelp, _("&Help") );
    SetMenuBar( menuBar );

    /* Status bar */

    CreateStatusBar();
   	SetStatusText("");

   	/* Status controls */
   	wxFlexGridSizer *grid;

   	wxPanel *panel = new wxPanel(this);

   	wxBoxSizer *cols = new wxBoxSizer(wxHORIZONTAL);

   	/* Status TextBox */
   	wxStaticBoxSizer *statusBox = new wxStaticBoxSizer(wxVERTICAL, panel, _("Status"));
   	grid = new wxFlexGridSizer(1, 2, 5, 5);
   	/* Microscope type */
   	grid->Add(new wxStaticText(statusBox->GetStaticBox(), wxID_ANY, _("Microscope type:")) );
   	stMicroType = new wxStaticText(statusBox->GetStaticBox(), wxID_ANY, "");
   	grid->Add(stMicroType);

   	statusBox->Add(grid, 0, 0);

   	cols->Add(statusBox, 0, wxALL, 5);

   	/* Probe TextBox */
   	wxStaticBoxSizer *probeBox = new wxStaticBoxSizer(wxVERTICAL, panel, _("Probe"));
   	grid = new wxFlexGridSizer(2, 2, 5, 5);

   	/* Height control mode */
   	grid->Add(new wxStaticText(probeBox->GetStaticBox(), wxID_ANY, _("Height control:")) );
   	stHeightControl = new wxStaticText(probeBox->GetStaticBox(), wxID_ANY, _("OFF"));
   	grid->Add(stHeightControl);
   	/* Height value */
   	grid->Add(new wxStaticText(probeBox->GetStaticBox(), wxID_ANY, _("Height:")) );
   	stHeightValue = new wxStaticText(probeBox->GetStaticBox(), wxID_ANY, "N/A");
   	grid->Add(stHeightValue);

   	probeBox->Add(grid, 0, 0);

   	cols->Add(probeBox, 0, wxALL, 5);

   	/* Scan TextBox */
   	wxStaticBoxSizer *scanBox = new wxStaticBoxSizer(wxVERTICAL, panel, _("Scan"));
   	btnStart = new wxButton(panel, ID_Run, _("Start"));
   	scanBox->Add(btnStart, 0, 0);

   	cols->Add(scanBox, 0, wxALL, 5);

   	panel->SetSizer(cols);

   	/* Update status */
   	tmrUpdate = new wxTimer(this, ID_UpdateTimer);
   	UpdateAFMState();
}

void MainFrame::UpdateAFMState()
{
	Device *afm;

	afm = wxGetApp().afm;

	if (!afm->IsConnected())
		afm->Connect();

	if (afm->IsConnected()) {
		afm->UpdateStatus();

	   	SetStatusText(_("Connected"));
	   	stMicroType->SetLabel(_("STM"));

	   	/* Restart update timer */
	   	tmrUpdate->StartOnce(UPDATE_TIMER_CONNECTED);
	} else {
	   	SetStatusText(_("Device is not connected or driver is not installed"));
	   	stMicroType->SetLabel("");

	   	/* Restart update timer */
	   	tmrUpdate->StartOnce(UPDATE_TIMER_DISCONNECTED);
	}
}

void MainFrame::OnExit(wxCommandEvent& event)
{
    Close( true );
}

void MainFrame::OnAbout(wxCommandEvent& event)
{
    wxMessageBox( _("Atomic Force Microscope control program."),
                  _("About"), wxOK | wxICON_INFORMATION );
}

void MainFrame::OnRun(wxCommandEvent& event)
{
	Device *afm;
	AFMImage *image;

	/* Start scanning */
	afm = wxGetApp().afm;
	if (!afm->Run(0, 0, 100, 100)) {
		wxMessageBox( _("Failed to start a scan. Check parameters and try again."),
				_("Scanning"), wxOK | wxICON_ERROR);
		return;
	}

	/* Create image object */
	image = new AFMImage();

	wxProgressDialog progress( _("Scanning"), _("Retrieving image data") );
	do {
		/* Read image from the device */
		if (!afm->ReadImage(image, NULL)) {
			wxMessageBox( _("Failed to retrieve scan image."),
					_("Scanning"), wxOK | wxICON_ERROR);
			break;
		}

		/* Hide progress dialog */
		progress.Update(100);

		/* Save file dialog */
		wxFileDialog saveFile(NULL, _("Save image"), "", "",
				"Gwyddion Simple Field (*.gsf)|*.gsf", wxFD_SAVE);

		if (saveFile.ShowModal() == wxID_CANCEL) break;

		/* Save image to file */
		image->SaveAsGSF(saveFile.GetFilename().ToStdString());
	} while (0);

	delete image;
}

void MainFrame::OnUpdateTimer(wxTimerEvent& evt)
{
	UpdateAFMState();
}

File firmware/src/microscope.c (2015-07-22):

/* Copyright (c) 2015 Vasily Voropaev <vvg@cubitel.org>
 *
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
 */

#include <stm32f4xx.h>

#include "microscope.h"

/* Hardware connections
 *
 * PA1	ADC_FOCUS		OPU focusing
 * PA2	ADC_IN			ADC Input signal
 * PA4	DAC_ZMODP		Cantilever modulation signal +
 * PA5	DAC_ZMODN		Cantilever modulation signal -
 * PA11	USBDM
 * PA12	USBDP
 *
 * PB3	CTL_CLK			SPI clock for VGA/VCM (SPI1)
 * PB5	CTL_SDI			SPI data for VGA/VCM (SPI1)
 * PB6	CTL_VGA			Variable gain amplifier chip select
 * PB7	ADC_SELECT		ADC_IN source select
 * PB8	CTL_VCM			Voice coil motor DAC chip select
 * PB9	VCM_MUTE		Voice coil motor MUTE signal
 * PB10	OPU_ENA			OPU laser enable signal
 * PB14	PZ_LDAC			Piezo DAC LDAC signal
 *
 * PC10	PZ_CLK			Piezo DAC SPI clock (I2S3)
 * PC11	PZ_CS			Piezo DAC chip select (I2S3_ext)
 * PC12	PZ_SDI			Piezo DAC SPI data (I2S3)
 *
 * PD12	STATUS_GR		Status green LED
 * PD13	STATUS_RD		Status red LED
 * PD14	PROBE_GR		Probe green LED
 * PD15	PROBE_RD		Probe red LED
 */

#define LED_STATUS_GRN	(1 << 12)
#define LED_STATUS_RED	(1 << 13)
#define LED_PROBE_GRN	(1 << 14)
#define LED_PROBE_RED	(1 << 15)

/* I2S PLL clock = PLLM (1 MHz) * N / R */
#define I2S_PLL_N		200		/* 192..432 */
#define I2S_PLL_R		2		/* 2..7 */
/* I2S clock = I2S PLL clock / (DIV * 2) */
#define I2S_DIV			16		/* 2..255 */

/* DAC channels */
#define DAC_X			0
#define DAC_Y			1
#define DAC_Z			2
#define DAC_BIAS		3

/* Piezo DAC DMA circular buffer
 * 3 words (X, Y, Z) and 16->20 bit DAC extension (x16)
 * give us 48 words buffer size
 */
#define DAC_VALUE_COUNT	16
#define DAC_BUFFER_SIZE	(DAC_VALUE_COUNT * 3)

/* High 16 bits are DAC value, low 2 bits are DAC channel */
static uint32_t dacDMABuffer[DAC_BUFFER_SIZE];
static uint32_t dacChipSelect = 0x0000FFFC;


/* Microscope configuration */
static config_t cfg;

/* DAC setpoints */
static uint32_t xSet;
static uint32_t ySet;
static uint32_t zSet;
static uint32_t biasSet;

/* ADC setpoint */
static uint32_t adcSet;


void DMA1_Stream7_IRQHandler(void);


static void gpioSetMode(GPIO_TypeDef *gpio, uint8_t pin, uint8_t mode)
{
	uint32_t mask;

	mask = 3 << (pin << 1);
	gpio->MODER = (gpio->MODER & ~mask) | (mode << (pin << 1));
}

static void gpioSetSpeed(GPIO_TypeDef *gpio, uint8_t pin, uint8_t speed)
{
	uint32_t mask;

	mask = 3 << (pin << 1);
	gpio->OSPEEDR = (gpio->OSPEEDR & ~mask) | (speed << (pin << 1));
}

static void gpioSetAltFunc(GPIO_TypeDef *gpio, uint8_t pin, uint8_t fn)
{
	uint32_t mask;

	gpioSetMode(gpio, pin, 2);

	if (pin < 8) {
		mask = 15 << (pin << 2);
		gpio->AFR[0] = (gpio->AFR[0] & ~mask) | (fn << (pin << 2));
	} else {
		pin &= 7;
		mask = 15 << (pin << 2);
		gpio->AFR[1] = (gpio->AFR[1] & ~mask) | (fn << (pin << 2));
	}
}

static void ledSet(uint32_t leds)
{
	GPIOD->ODR = (GPIOD->ODR & ~(LED_STATUS_GRN | LED_STATUS_RED | LED_PROBE_GRN | LED_PROBE_RED)) | leds;
}

static void fillDACBuffer(uint32_t *buf)
{
	int i;
	uint32_t x, y, z;
	uint32_t zdev;
	uint32_t adc;

	switch (cfg.zcontrol) {
	case AFM_ZCONTROL_OFF:
		xSet = 0x80000000;
		ySet = 0x80000000;
		zSet = 0x80000000;
		break;
	case AFM_ZCONTROL_ON:
		if (ADC1->SR & ADC_SR_EOC) {
			adc = ADC1->DR;
			zdev = 0x00001000;
			/* Probe is lower */
			if (adc > adcSet) {
				if (zSet < (0xFFFFFFFF - zdev)) zSet += zdev;
			}
			/* Probe is higher */
			if (adc < adcSet) {
				if (zSet > zdev) zSet -= zdev;
			}
		}
		/* Start new conversation on ADC1 */
		ADC1->CR2 |= ADC_CR2_SWSTART;
		break;
	}

	x = xSet;
	y = ySet;
	z = zSet;

	/* Fill buffer with sigma-delta modulated values */
	for (i = 0; i < DAC_VALUE_COUNT; i++) {
		x = (x & 0xFFFF) + xSet;
		*buf++ = (x & 0xFFFF0000) | DAC_X;
		y = (y & 0xFFFF) + ySet;
		*buf++ = (y & 0xFFFF0000) | DAC_Y;
		z = (z & 0xFFFF) + zSet;
		*buf++ = (z & 0xFFFF0000) | DAC_Z;
	}
}

static void dacStart(void)
{
	fillDACBuffer(dacDMABuffer);

	/* Start SPI3 */
	DMA1_Stream7->CR |= DMA_SxCR_EN;
	DMA1_Stream5->CR |= DMA_SxCR_EN;
	I2S3ext->I2SCFGR |= SPI_I2SCFGR_I2SE;
	SPI3->I2SCFGR |= SPI_I2SCFGR_I2SE;
}

void micInit()
{
	/* Default configuration */
	cfg.micType = AFM_TYPE_STM;
	cfg.zcontrol = AFM_ZCONTROL_OFF;
	cfg.afm.amplitude = 75;
	cfg.afm.freq = 0;
	cfg.stm.bias = 50;
	cfg.stm.current = 100;

	/* Zero DAC outputs */
	xSet = 0x80000000;
	ySet = 0x80000000;
	zSet = 0x80000000;
	biasSet = 0x80000000;
	adcSet = 1000;

	/***** Configure hardware *****/

	/* Enable peripheral clocks */
	RCC->AHB1ENR |= RCC_AHB1ENR_GPIOAEN | RCC_AHB1ENR_GPIOBEN | RCC_AHB1ENR_GPIOCEN | RCC_AHB1ENR_GPIODEN | RCC_AHB1ENR_DMA1EN;

	/* PA2 -- ADC IN 2, Analog */
	gpioSetMode(GPIOA, 2, 3);
	/* PA15 -- I2S3_WS (Not connected, but needed for I2S3ext) */
	gpioSetAltFunc(GPIOA, 15, 6);
	gpioSetSpeed(GPIOA, 15, 2);

	/* PC10 -- I2S3_CK, Fast */
	gpioSetAltFunc(GPIOC, 10, 6);
	gpioSetSpeed(GPIOC, 10, 2);
	/* PC11 -- I2S3ext_SD, Fast */
	gpioSetAltFunc(GPIOC, 11, 5);
	gpioSetSpeed(GPIOC, 11, 2);
	/* PC12 -- I2S3_SD, Fast */
	gpioSetAltFunc(GPIOC, 12, 6);
	gpioSetSpeed(GPIOC, 12, 2);

	/* PD12..PD15 -- Outputs */
	gpioSetMode(GPIOD, 12, 1);
	gpioSetMode(GPIOD, 13, 1);
	gpioSetMode(GPIOD, 14, 1);
	gpioSetMode(GPIOD, 15, 1);

	/* Configure SPI3
	 *
	 * "Thanks" to ST which ignores CKPOL bit in PCM mode and makes it unusable here.
	 * So, we use SPI3 in I2S full-duplex with both channels in transmit mode.
	 * I2S3_SD used for data line, and I2S3ext_SD used for chip select line.
	 */

	/* Enable SPI3 */
	RCC->APB1ENR |= RCC_APB1ENR_SPI3EN;
	/* I2S clock source -- PLL */
	RCC->CFGR &= ~RCC_CFGR_I2SSRC;
	/* Set PLL frequency */
	RCC->PLLI2SCFGR = (I2S_PLL_R << 28) | (I2S_PLL_N << 6);
	/* Enable I2S PLL */
	RCC->CR |= RCC_CR_PLLI2SON;
	/* Wait for PLL ready */
	while (!(RCC->CR & RCC_CR_PLLI2SRDY)) {}
	/* I2S prescaler */
	SPI3->I2SPR = I2S_DIV;
	/* I2S mode, master, transmit, 32 bit */
	SPI3->I2SCFGR = SPI_I2SCFGR_I2SMOD | SPI_I2SCFGR_I2SCFG_1 | SPI_I2SCFGR_I2SSTD_0 | SPI_I2SCFGR_DATLEN_1;
	/* I2Sext, slave, transmit, 32 bit */
	I2S3ext->I2SCFGR = SPI_I2SCFGR_I2SMOD | SPI_I2SCFGR_I2SSTD_0 | SPI_I2SCFGR_DATLEN_1;

	/* DMA setup: Channel 0, Memory to peripheral, 16 bit, circular mode, transfer complete interrupt */
	DMA1_Stream7->CR = DMA_SxCR_PSIZE_0 | DMA_SxCR_MSIZE_0 | DMA_SxCR_MINC | DMA_SxCR_CIRC | DMA_SxCR_DIR_0 | DMA_SxCR_TCIE;
	/* DMA buffer start address */
	DMA1_Stream7->M0AR = (uint32_t)dacDMABuffer;
	/* Destination -- SPI3 DR */
	DMA1_Stream7->PAR = (uint32_t)&SPI3->DR;
	/* Data items count */
	DMA1_Stream7->NDTR = DAC_BUFFER_SIZE * 2;
	/* Disable direct mode */
	DMA1_Stream7->FCR = DMA_SxFCR_DMDIS;

	/* DMA setup: Channel 2, Memory to peripheral, 16 bit, circular mode */
	DMA1_Stream5->CR = (2 << 25) | DMA_SxCR_PSIZE_0 | DMA_SxCR_MSIZE_0 | DMA_SxCR_MINC | DMA_SxCR_CIRC | DMA_SxCR_DIR_0;
	/* DMA buffer start address */
	DMA1_Stream5->M0AR = (uint32_t)&dacChipSelect;
	/* Destination -- I2S3ext DR */
	DMA1_Stream5->PAR = (uint32_t)&I2S3ext->DR;
	/* Data items count */
	DMA1_Stream5->NDTR = 2;
	/* Disable direct mode */
	DMA1_Stream5->FCR = DMA_SxFCR_DMDIS;
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

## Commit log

2015-07-22 Piezo DAC moved from SPI2 to SPI3
    [afm.kicad_pcb, mcu.sch]
2015-07-24 PCB trace completed
    [afm.kicad_pcb]
2015-08-08 Changed origin point
    [preamp.kicad_pcb]

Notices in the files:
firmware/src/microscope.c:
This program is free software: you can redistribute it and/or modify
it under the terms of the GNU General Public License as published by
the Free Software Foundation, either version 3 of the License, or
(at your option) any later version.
